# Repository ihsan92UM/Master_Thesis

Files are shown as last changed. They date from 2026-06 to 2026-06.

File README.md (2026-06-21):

# Master_Thesis

## Repository Structure
```
Master_Thesis/
├── graphics/
│   └── Contains all .png images used in markdown files
├── pcb_design_files/
│   └── Contains KiCAD 9.0 files 
├── programming_guides/
│   └── Contains programming setup and code import guide
├── stm32c0_codes/
    └── Demo code for funtional board incl. USB, I2C.
```

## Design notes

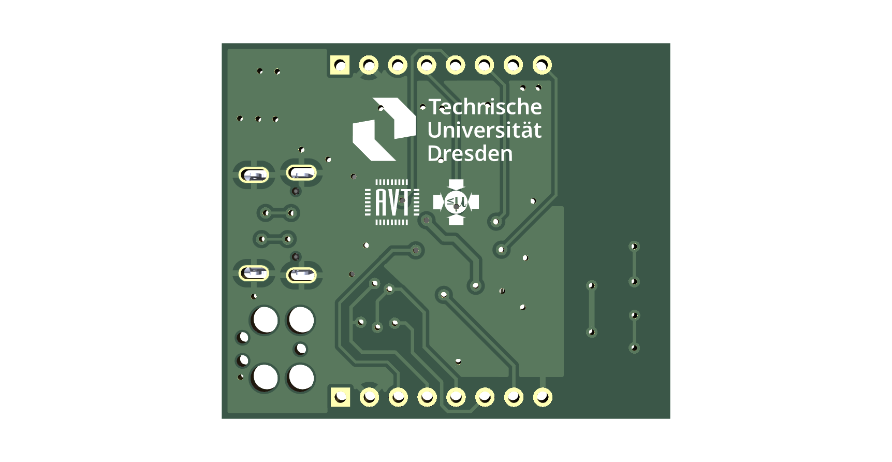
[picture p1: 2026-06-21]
pcb_design_files/func_board_jlcpcb/func_board_back_white_bw.png

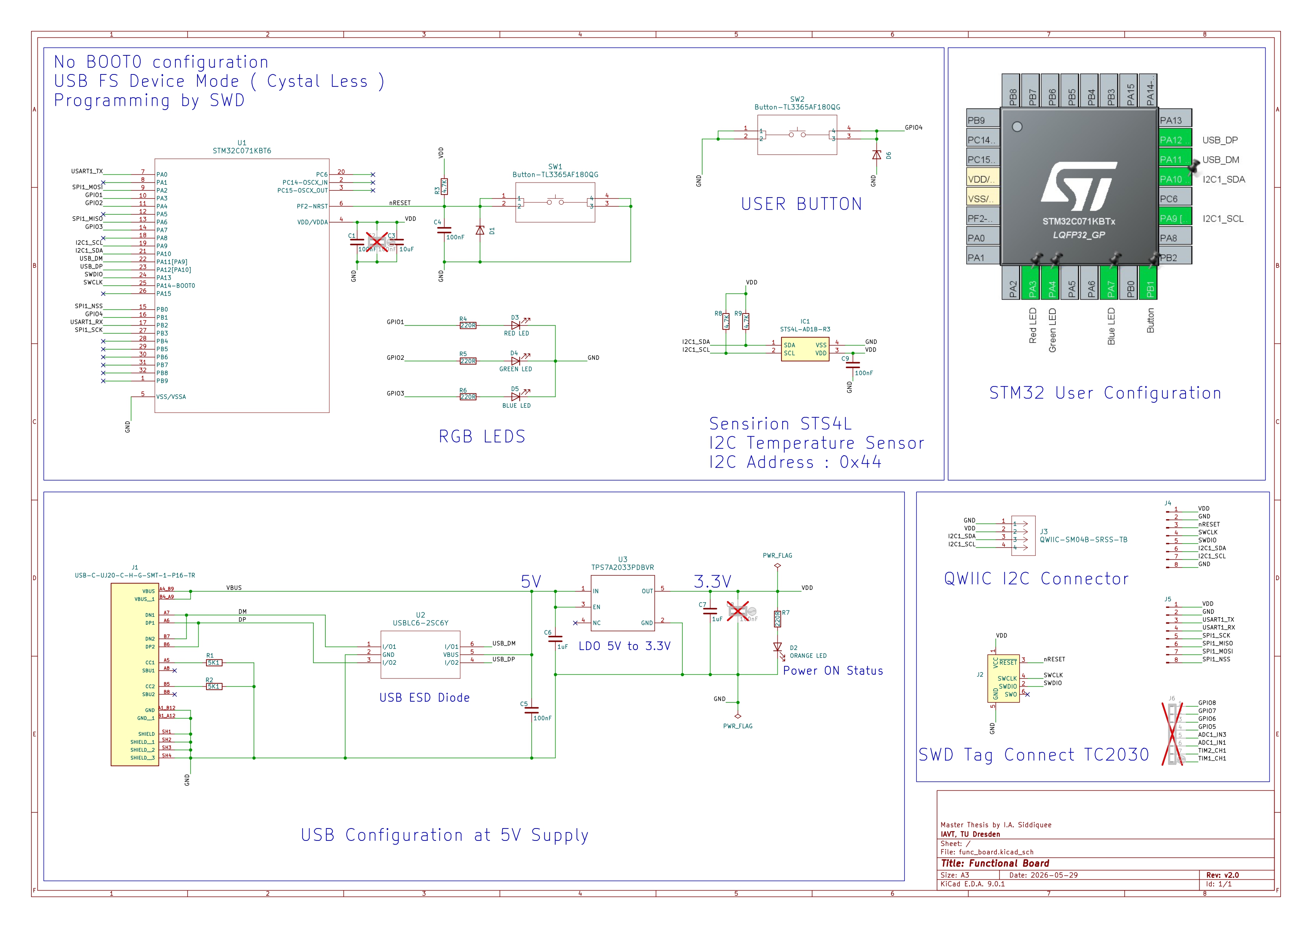
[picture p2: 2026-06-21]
pcb_design_files/func_board_jlcpcb/func_board_schematic.jpg

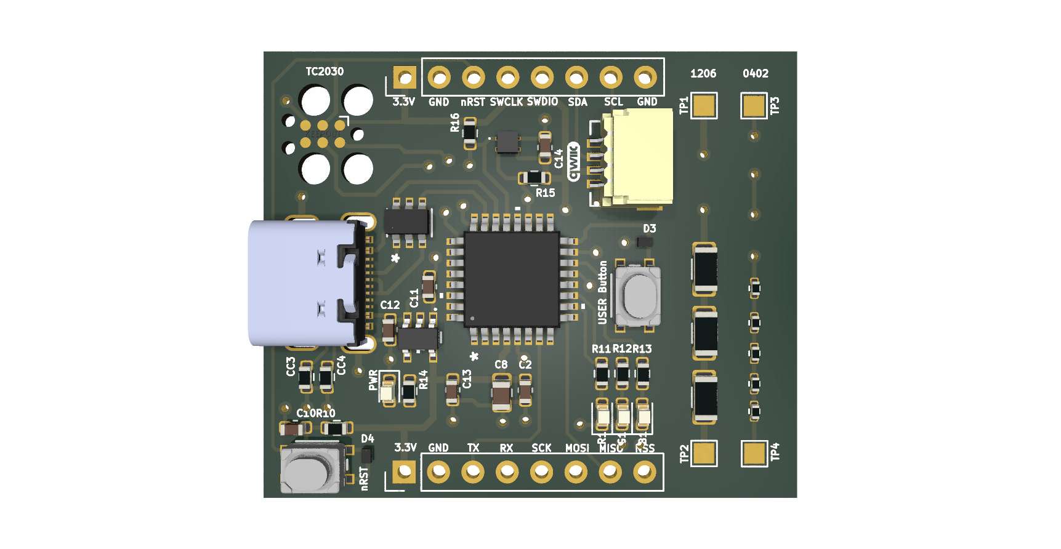
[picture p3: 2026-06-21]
pcb_design_files/func_board_jlcpcb/func_board_front_white_bw.png

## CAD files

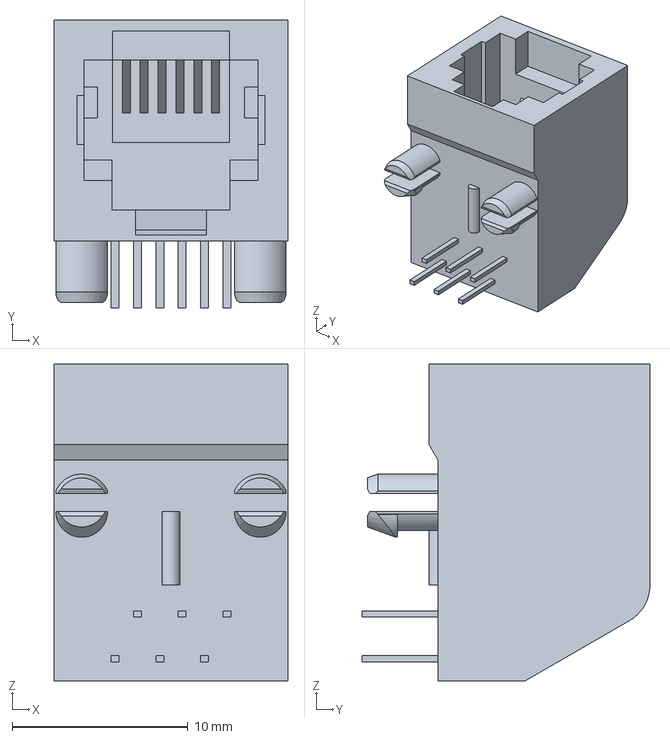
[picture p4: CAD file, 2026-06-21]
pcb_design_files/func_board_jlcpcb/Cad_files/5555165_1/c-5555165-1-e-3d.stp
13.3 x 16.4 x 18.0 mm

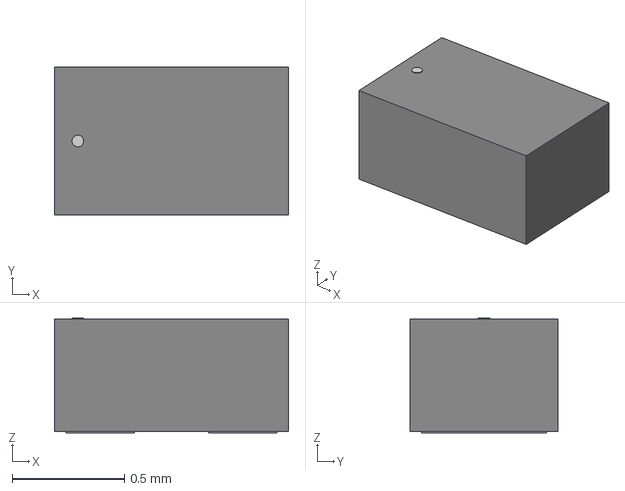
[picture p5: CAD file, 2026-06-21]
pcb_design_files/func_board_jlcpcb/Cad_files/ESDALC6V1_1M2/SOD882_STM.step
1.04 x 0.66 x 0.511 mm

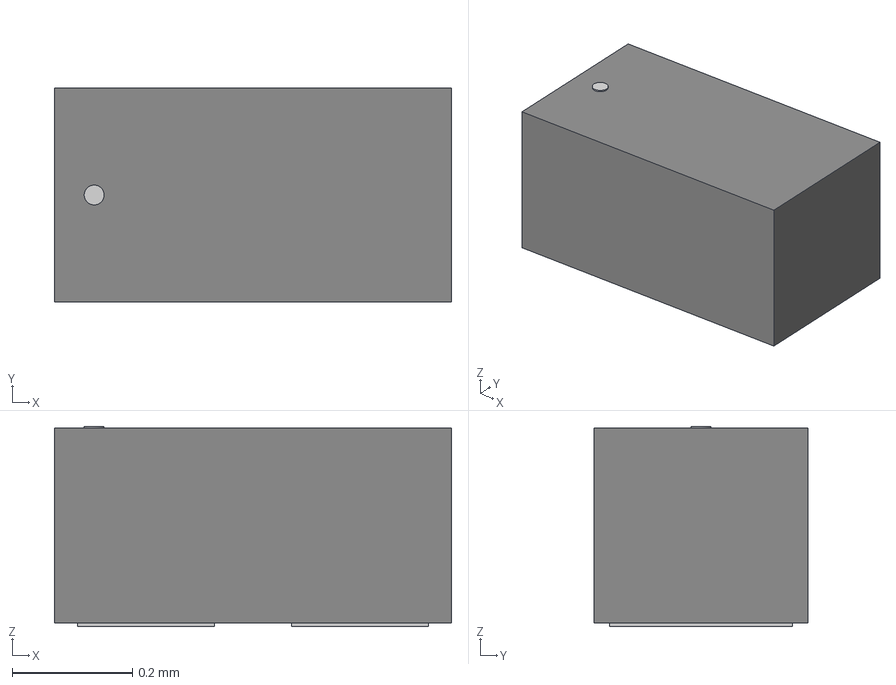
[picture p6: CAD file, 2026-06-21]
pcb_design_files/func_board_jlcpcb/Cad_files/ESDALC6V1_1U2/DIODE_ESDALC6V1-1U2_STM.step
0.66 x 0.356 x 0.333 mm

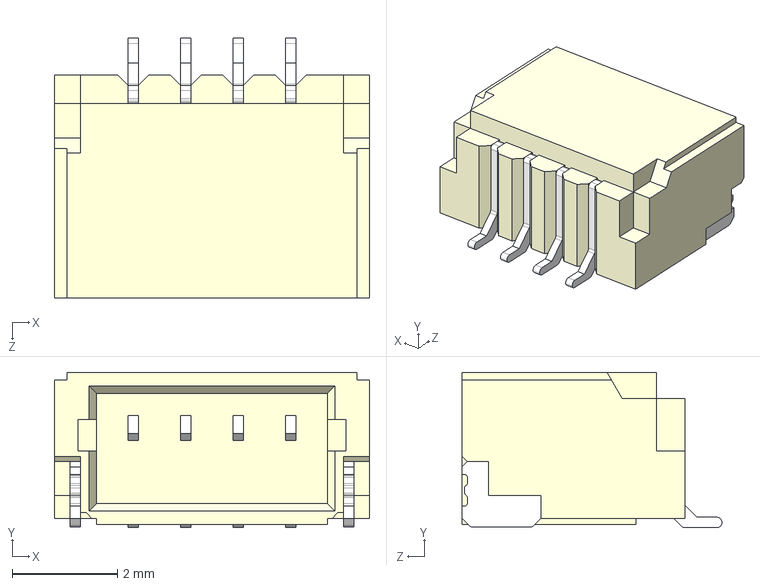
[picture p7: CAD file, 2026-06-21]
pcb_design_files/func_board_jlcpcb/Cad_files/SM04B_SRSS_TB/SM04B-SRSS-TB (LF)(SN)--3DModel-STEP-269445.STEP
6.00 x 2.96 x 4.95 mm

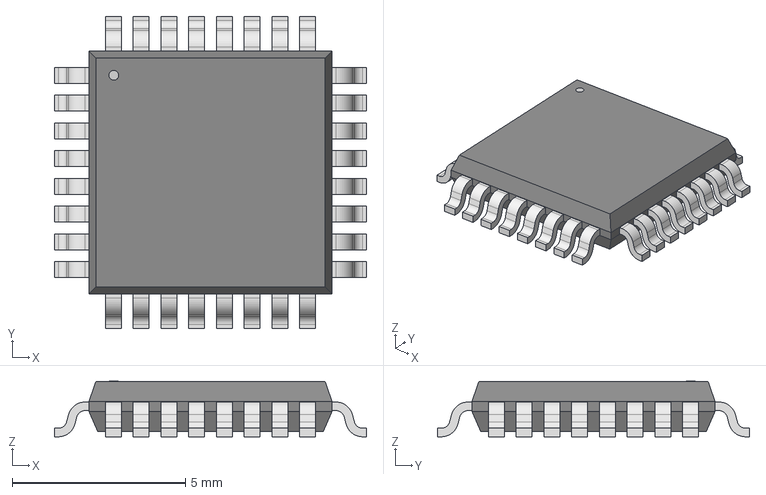
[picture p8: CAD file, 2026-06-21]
pcb_design_files/func_board_jlcpcb/Cad_files/STM32C071KBT6/LQFP-32_STM.step
8.99 x 8.99 x 1.60 mm

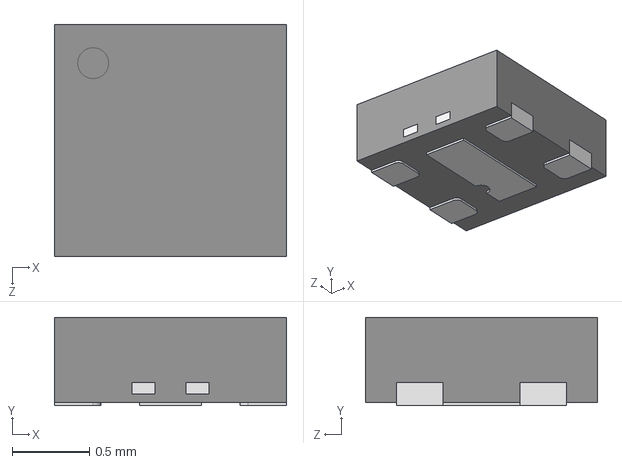
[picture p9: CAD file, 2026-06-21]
pcb_design_files/func_board_jlcpcb/Cad_files/STS40_CD1B_R3/STS40-CD1B-R3.STEP
1.50 x 0.57 x 1.50 mm

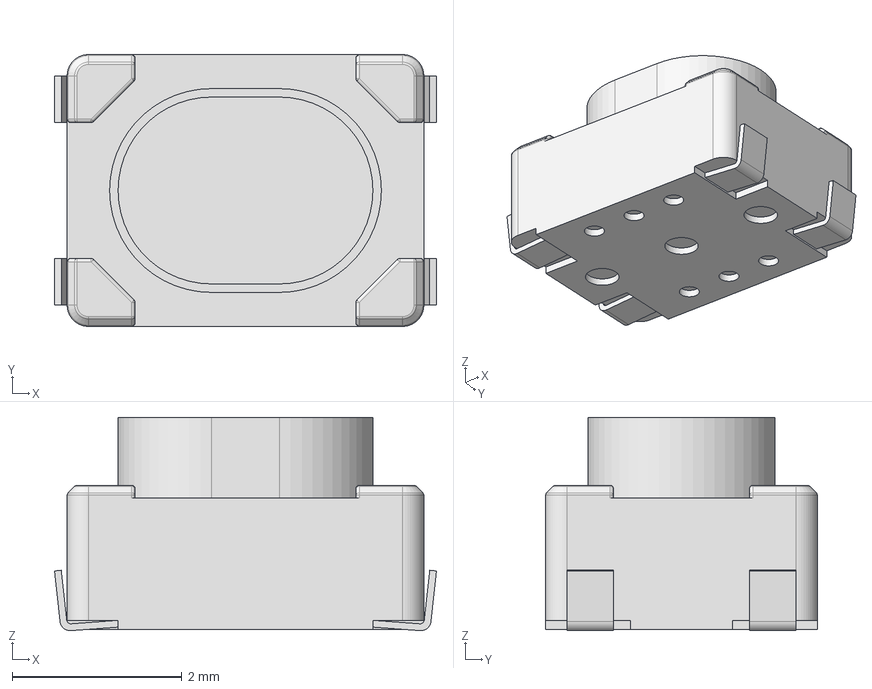
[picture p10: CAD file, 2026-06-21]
pcb_design_files/func_board_jlcpcb/Cad_files/TL3365AF180QG/TL3365AF180QG.stp
4.50 x 3.20 x 2.51 mm

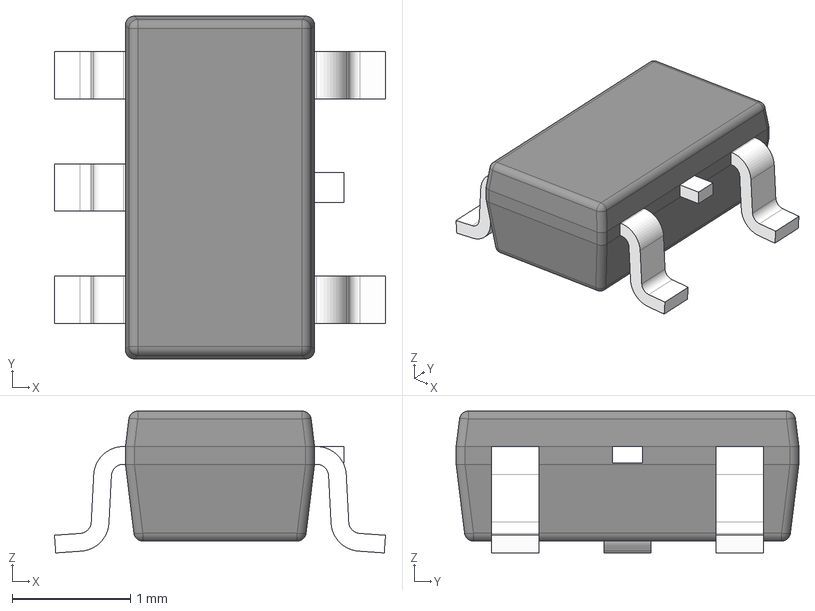
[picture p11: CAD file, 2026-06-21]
pcb_design_files/func_board_jlcpcb/Cad_files/TPS7A2033PDBVR/DBV0005A.stp
2.80 x 2.90 x 1.20 mm
BODY-SOT
LEAD-SOT x 5
LEAD-DUMMY

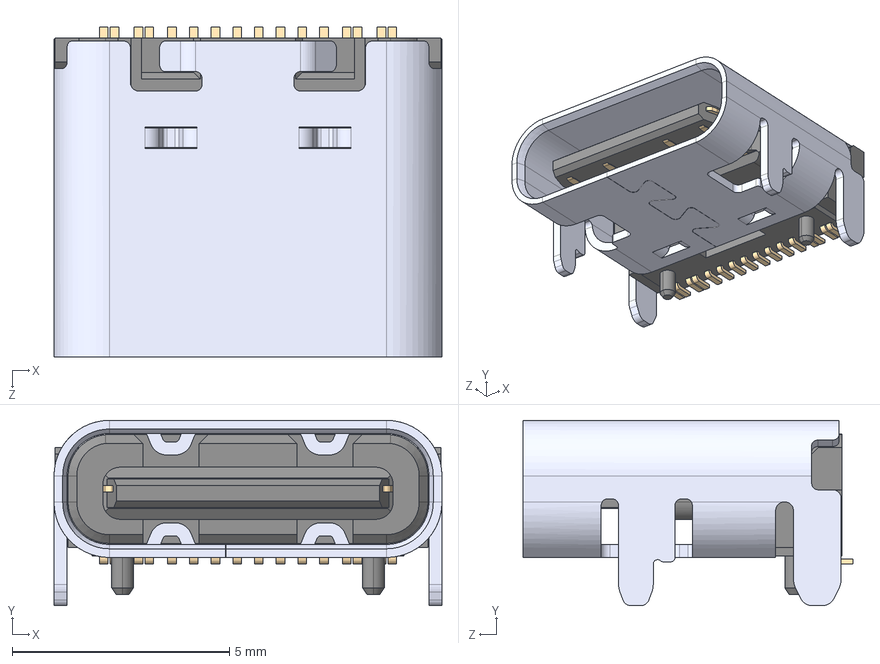
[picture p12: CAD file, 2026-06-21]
pcb_design_files/func_board_jlcpcb/Cad_files/UJ20_C_H_G_SMT_1_P16_TR/UJ20-C-H-G-SMT-1-P16-TR.step
8.94 x 4.27 x 7.60 mm

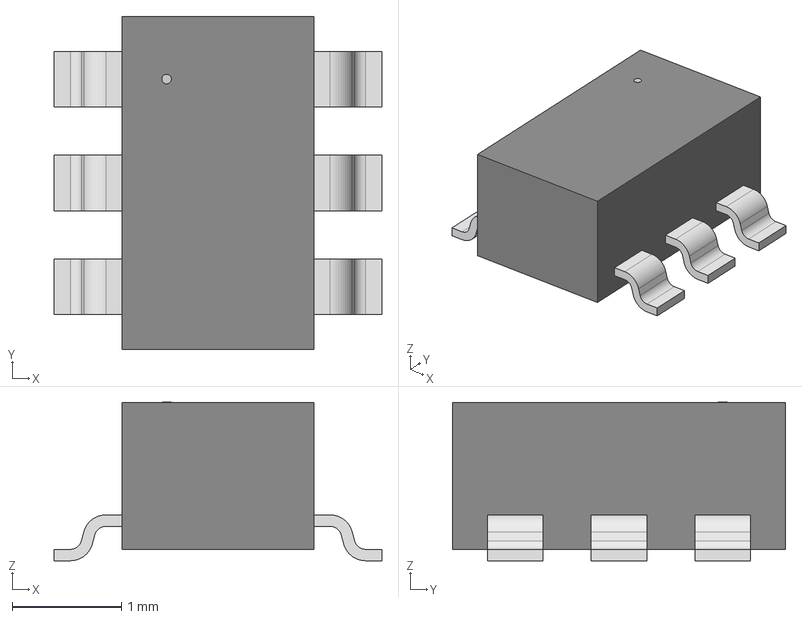
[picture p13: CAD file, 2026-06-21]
pcb_design_files/func_board_jlcpcb/Cad_files/USBLC6_2SC6Y/SOT23-6L_STM.step
3.00 x 3.05 x 1.45 mm

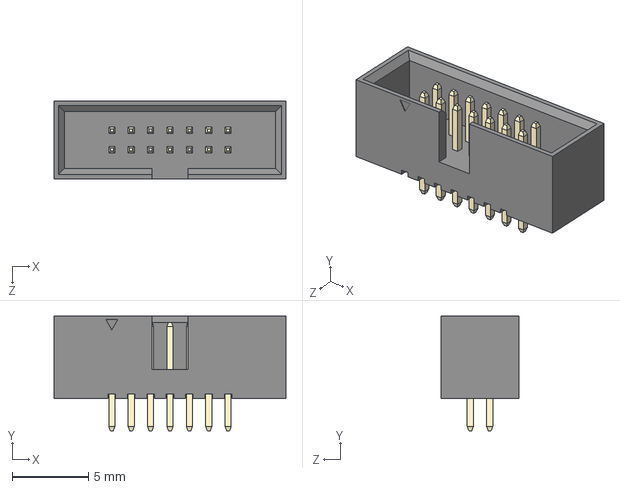
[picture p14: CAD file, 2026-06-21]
pcb_design_files/programmer_bridge/step file/3220-14-0100-00.STEP
15.2 x 7.50 x 5.10 mm
3220-xx-0100-00 body_14
Pin^3220-xx-0100-00 x 14

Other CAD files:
pcb_design_files/func_board_jlcpcb/Cad_files/LIB_STS4L-AD1B-R3/STS4L-AD1B-R3/Allegro/sts4lad1br3.psm
pcb_design_files/func_board_jlcpcb/Cad_files/LIB_STS4L-AD1B-R3/STS4L-AD1B-R3/DEHDL/sts4l_ad1b_r3/chips/chips.prt

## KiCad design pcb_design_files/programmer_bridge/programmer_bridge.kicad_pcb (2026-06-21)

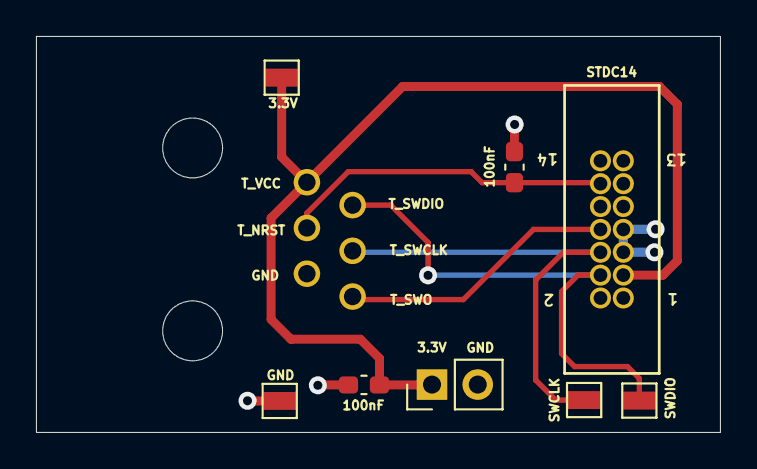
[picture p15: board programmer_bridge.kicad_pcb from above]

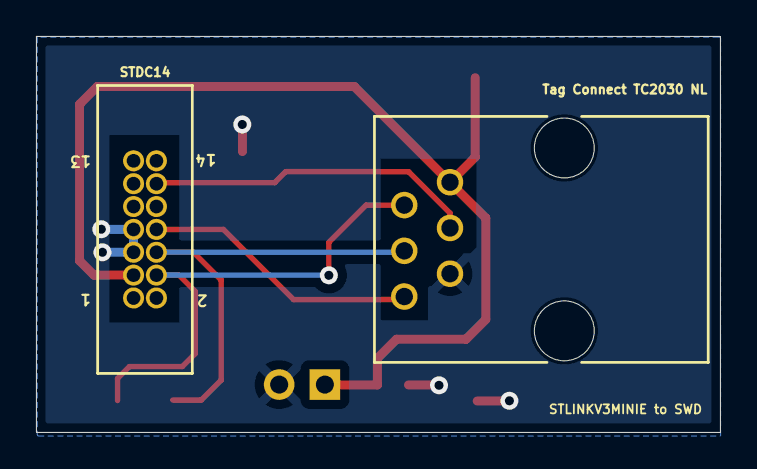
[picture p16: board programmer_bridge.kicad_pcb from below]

Board: 2 copper layers, 38.0 x 22.0 mm, 9 parts (2 on the bottom side), 6 nets.

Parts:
C4, C5: 100nF; C_0603_1608Metric_Pad1.08x0.95mm_HandSolder
J1: 5555165-1; CONN6_5555165-1_TEC
J2: 3220-14-0100-00; CONN14_3220-14_CNC
J3: Conn_01x02_Pin; PinHeader_1x02_P2.54mm_Vertical
SWCLK: TestPoint; TestPoint_Pad_1.5x1.5mm
SWDIO: TestPoint; TestPoint_Pad_1.5x1.5mm
TP3, TP6: TestPoint; TestPoint_Pad_1.5x1.5mm

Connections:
/GND: C4.2, C5.2, J1.2, J2.5, J2.7, J3.2, TP3.1
/T_NRST: C5.1, J1.4, J2.12
/T_SWCLK: J1.3, J2.6, SWCLK.1
/T_SWDIO: J1.5, J2.4, SWDIO.1
/T_SWO: J1.1, J2.8
/T_VCC: C4.1, J1.6, J2.3, J3.1, TP6.1

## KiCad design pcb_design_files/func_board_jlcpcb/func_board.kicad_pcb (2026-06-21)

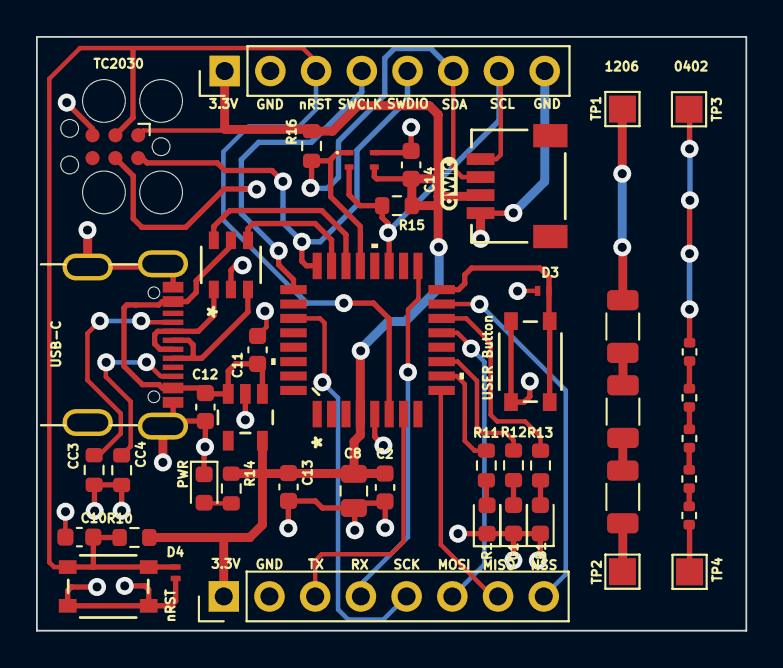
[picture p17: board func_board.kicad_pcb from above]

Board: 2 copper layers, 39.4 x 33.0 mm, 33 parts (0 on the bottom side), 28 nets.

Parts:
B1: BLUE LED; LED_0603_1608Metric
C2, C10, C11, C14: 100nF; C_0603_1608Metric
C8: 10uF; C_0805_2012Metric
C12, C13: 1uF; C_0603_1608Metric
CC3, CC4: 5K1; R_0603_1608Metric
D3, D4: ESD5Zxx; ESDALC6V1_1M2
G1: GREEN LED; LED_0603_1608Metric
IC2: STS4L-AD1B-R3; STS4LAD1BR3
J6: Conn_ARM_SWD_TagConnect_TC2030; Tag-Connect_TC2030-IDC-FP_2x03_P1.27mm_Vertical
J7: QWIIC-SM04B-SRSS-TB; CONN_SM04B-SRSS-TB_JST
J8, J9: Conn_01x08_Pin; PinHeader_1x08_P2.54mm_Vertical
PWR1: ORANGE LED; LED_0603_1608Metric
R1: RED LED; LED_0603_1608Metric
R10, R15, R16: 4.7K; R_0603_1608Metric
R11, R12, R13, R14: 220R; R_0603_1608Metric
SW3, SW4: Button-TL3365AF180QG; TL3365AF180QG_EWI
U4: STM32C071KBT6; LQFP-32_STM
U5: USBLC6-2SC6Y; SOT23-6L_STM
U6: TPS7A2033PDBVR; DBV0005A-MFG
USB-C1: USB-C-UJ20-C-H-G-SMT-1-P16-TR; SAMESKY_UJ20-C-H-G-SMT-1-P16-TR

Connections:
/DM: U5.1 (I/O1), USB-C1.A7 (DN1), USB-C1.B7 (DN2)
/DP: U5.3 (I/O2), USB-C1.A6 (DP1), USB-C1.B6 (DP2)
/GND: B1.1 (K), C2.2, C8.2, C10.2, C11.2, C12.2, C13.2, C14.2, CC3.2, CC4.2, D3.2 (A), D4.2 (A), G1.1 (K), IC2.4 (VSS), J6.5 (GND), J7.1, J8.2, J8.8, J9.2, PWR1.1 (K), R1.1 (K), SW3.3, SW3.4, SW4.1, SW4.2, U4.5 (VSS/VSSA), U5.2 (GND), U6.2 (GND), USB-C1.A1_B12 (GND), USB-C1.B1_A12 (GND__1), USB-C1.SH1 (SHIELD), USB-C1.SH2 (SHIELD__1), USB-C1.SH3 (SHIELD__2), USB-C1.SH4 (SHIELD__3)
/GPIO1: R11.1, U4.10 (PA3)
/GPIO2: R12.1, U4.11 (PA4)
/GPIO3: R13.1, U4.14 (PA7)
/GPIO4: D3.1 (K), SW4.3, SW4.4, U4.16 (PB1)
/I2C2_SCL: IC2.2 (SCL), J7.4, J8.7, R15.2, U4.19 (PA9)
/I2C2_SDA: IC2.1 (SDA), J7.3, J8.6, R16.2, U4.21 (PA10)
/SPI1_MISO: J9.6, U4.13 (PA6)
/SPI1_MOSI: J9.7, U4.9 (PA2)
/SPI1_NSS: J9.8, U4.15 (PB0)
/SPI1_SCK: J9.5, U4.27 (PB3)
/SWCLK: J6.4 (SWCLK), J8.4, U4.25 (PA14-BOOT0)
/SWDIO: J6.2 (SWDIO), J8.5, U4.24 (PA13)
/USART1_RX: J9.4, U4.17 (PB2)
/USART1_TX: J9.3, U4.7 (PA0)
/USB_DM: U4.22 (PA11[PA9]), U5.6 (I/O1)
/USB_DP: U4.23 (PA12[PA10]), U5.4 (I/O2)
/VBUS: C11.1, C12.1, U5.5 (VBUS), U6.1 (IN), U6.3 (EN), USB-C1.A4_B9 (VBUS), USB-C1.B4_A9 (VBUS__1)
/VDD: C2.1, C8.1, C13.1, C14.1, IC2.3 (VDD), J6.1 (VCC), J7.2, J8.1, J9.1, R10.2, R14.1, R15.1, R16.1, U4.4 (VDD/VDDA), U6.5 (OUT)
/nRESET: C10.1, D4.1 (K), J6.3 (~RESET), J8.3, R10.1, SW3.1, SW3.2, U4.6 (PF2-NRST)
unnamed: PWR1.2 (A), R14.2
unnamed: R1.2 (A), R11.2
unnamed: G1.2 (A), R12.2
unnamed: B1.2 (A), R13.2
unnamed: CC3.1, USB-C1.A5 (CC1)
unnamed: CC4.1, USB-C1.B5 (CC2)

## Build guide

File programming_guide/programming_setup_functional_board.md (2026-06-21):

# Programming Guide - STM32C071KBT6 based functional board 

## Requirements

#### Hardware

* Programmer : [STLINK-V3MINIE](https://www.st.com/resource/en/user_manual/um2910-stlinkv3minie-debuggerprogrammer-tiny-probe-for-stm32-microcontrollers-stmicroelectronics.pdf)
* Type-C cable
* Functional Board
* Programmer bridge
* [Tag Connect TC2030-MCP](https://www.digikey.de/de/products/detail/tag-connect-llc/TC2030-MCP/2666488)

#### Software
* [STM32CubeIDE 1.17.0](https://www.st.com/en/development-tools/stm32cubeide.html)
* [STM3CubeProgrammer](https://www.st.com/en/development-tools/stm32cubeprog.html)

# Getting Started
To program the functional board using SWD, first connect the STLINK-V3MINIE STDC14 cable to Programmer Bridge boards Female STDC14 connector. Then, Tag Connect TC2030's RJ12 Jack to the Programmer Bridge boards Female RJ12 receptor. Finally, the Tag Connect's 6pin connector to the functional board.

> [!IMPORTANT]
> Functional board has to be powered by USB-C because the STLINKV3MINIE programmer doesn't provide the board with power. The Programmer only senses the VDD and GND levels. 

Connection diagram

# Setup Validation

## STM32CubeProgrammer 

Open the `STM32CubeProgrammer` application and select `STLINK` as Interface and `Connect`. Once connected on the `Target Information` window it will list the MCU that is connected. On the `ST-LINK configuration` window it will show the target voltage level.

## Porgramming

Device can be now programmed as usual as using STM32CubeIDE.

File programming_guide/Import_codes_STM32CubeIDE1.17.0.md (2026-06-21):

# Importing Existing Code — STM32CubeIDE 1.17.0

## Requirements

### Hardware
- Functional board
- STLINK-V3MINIE programmer and Programmer Bridge
- Type-C cable

### Software
- [STM32CubeIDE 1.17.0](https://www.st.com/en/development-tools/stm32cubeide.html)
- [STM32CubeMX](https://www.st.com/en/development-tools/stm32cubemx.html)
- [STM32CubeProgrammer](https://www.st.com/en/development-tools/stm32cubeprog.html)

## Software Basics

- **STM32CubeIDE 1.17.0**: An integrated development environment (IDE) used to write, compile, debug, and run code on STM32 microcontrollers.
- **STM32CubeMX**: A graphical configuration tool for setting up pins, peripherals, and middleware, and generating initialization code for use in STM32CubeIDE.

These two tools complement each other. STM32CubeMX is typically opened within STM32CubeIDE to configure the target and generate the `.ioc` file.

# Getting Started

Download and install all three required software packages, then open **STM32CubeIDE 1.17.0**.

> [!WARNING]
> Existing STM32 code in this project was written using STM32CubeIDE version 1.17.0. Newer versions can be used, but the code may need to be migrated.

# Importing a Sample Programme

1. Launch STM32CubeIDE 1.17.0 and choose a folder as your workspace directory.  
   Workspace selection

2. After selecting the preferred folder, the STM32CubeIDE user interface will load.  
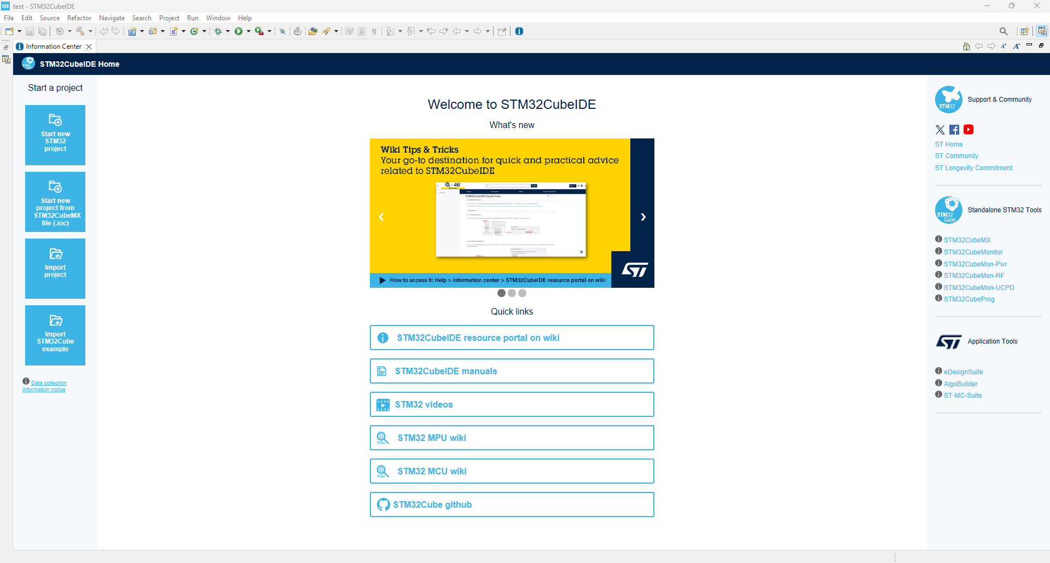
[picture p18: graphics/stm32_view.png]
STM32 default view
   

3. From the start screen, select **Import project**.  
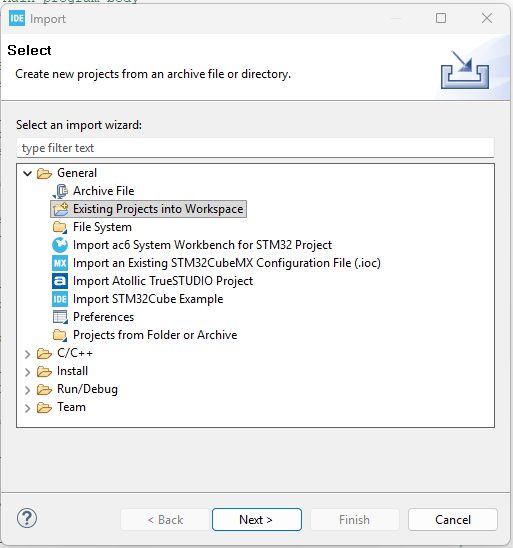
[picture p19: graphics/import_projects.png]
Import project selection
   

4. Navigate to the functional board demo code and select the options shown below.  
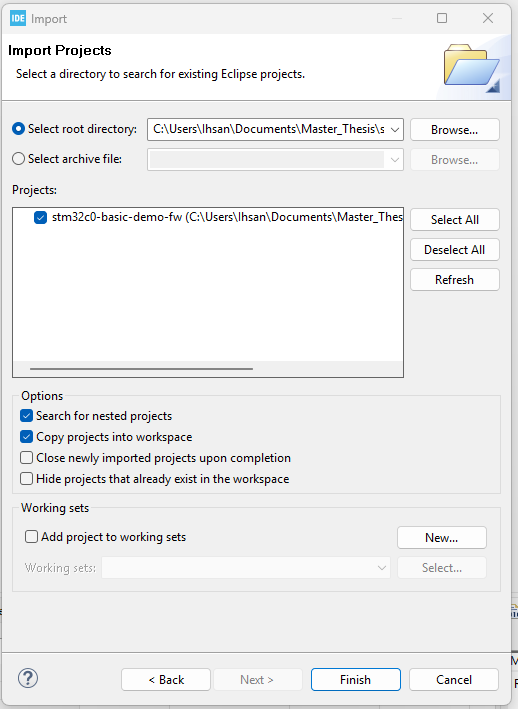
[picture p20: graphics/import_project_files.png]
File selection
   

5. Click **Finish**.

6. The project will open as **stm32c0-basic-demo-fw** in STM32CubeIDE. Navigate to the **Src** folder and open `main.c` to activate the build option.  
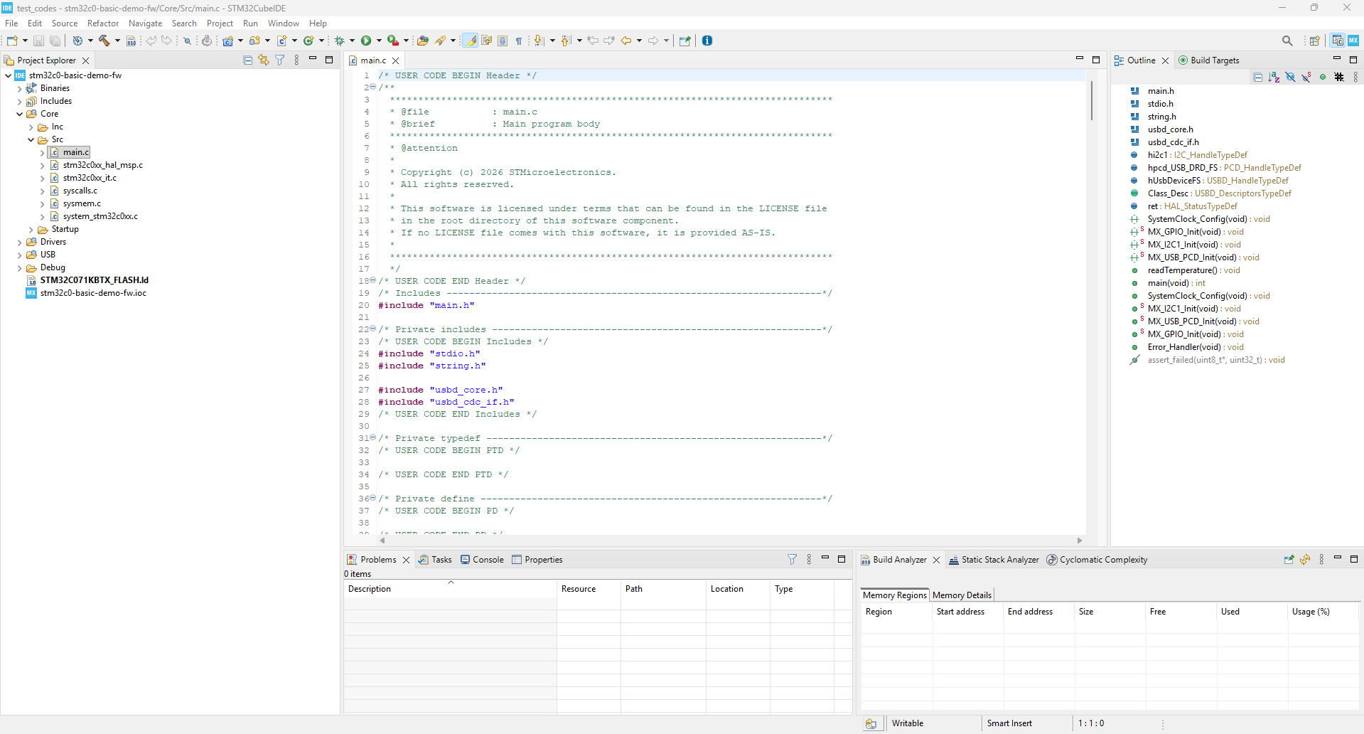
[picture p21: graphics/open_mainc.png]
Project explorer
   

7. Once `main.c` is opened, the build option becomes active. It is shown as a small hammer icon.  
   Build file

8. Click the build option to compile the code.  
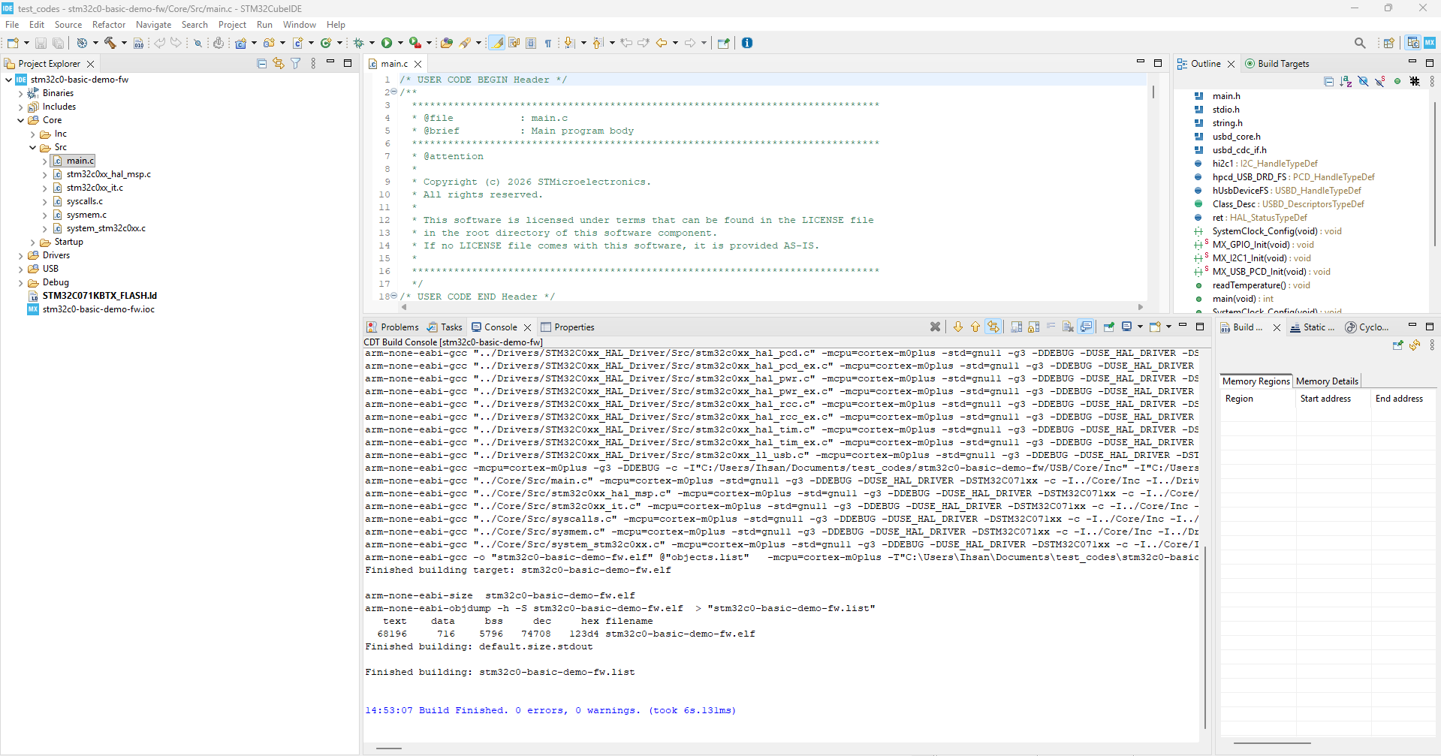
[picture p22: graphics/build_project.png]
Build console
   

9. Select the project and click **Debug** to open the debug configuration window. In the **Main** tab, the build configuration name is automatically set to the project name.  
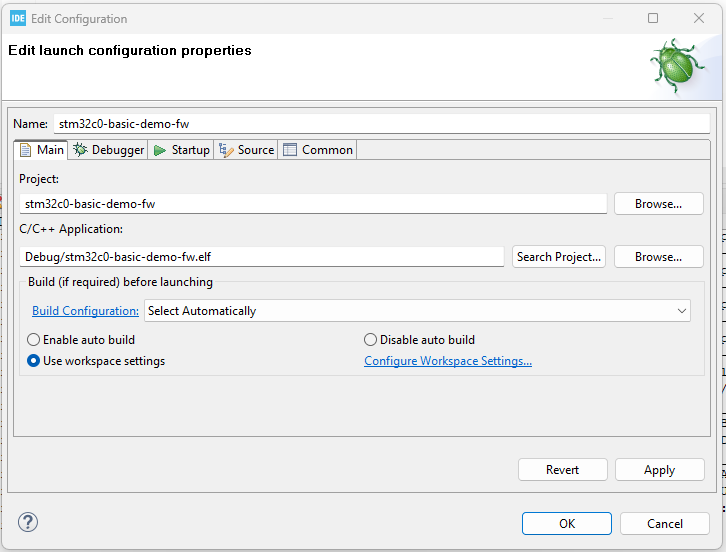
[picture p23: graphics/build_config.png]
Build configuration
   

10. Open the **Debugger** tab, select the **SWD** interface, tick **ST-LINK S/N**, click **Scan** for the Nucleo board, then click **Apply** and **OK**.  
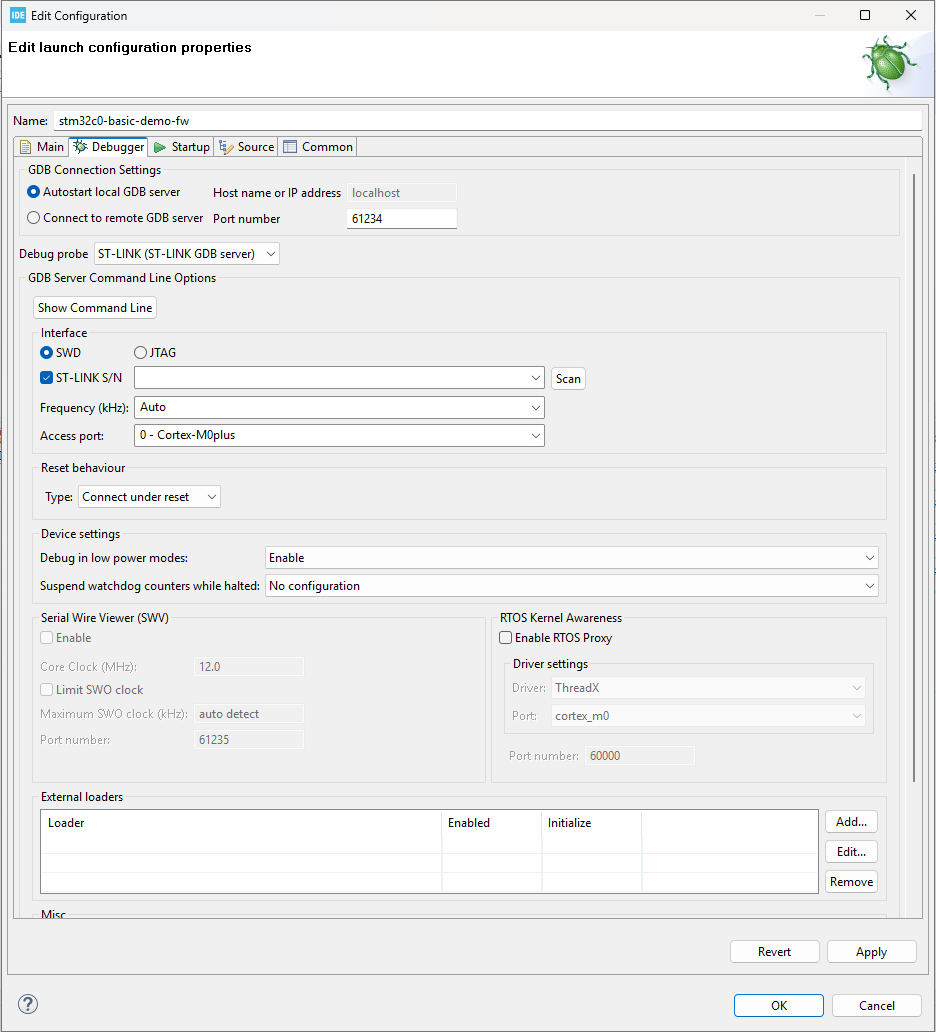
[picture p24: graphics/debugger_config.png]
Debugger configuration
    

11. The IDE will now generate and build the code before flashing it to the board. Once flashing is complete, the **Debug perspective** will open.

12. Navigate in the Debug window and step from `HAL_Init();` using the debug controls at the top of the window.

13. Stop the debugging session by clicking **Stop**. The board will then run normally.

> Note: Sometimes the USB code may fail to initialize during a debug session because step-by-step debugging is enabled. No fix has been added in the demo code.

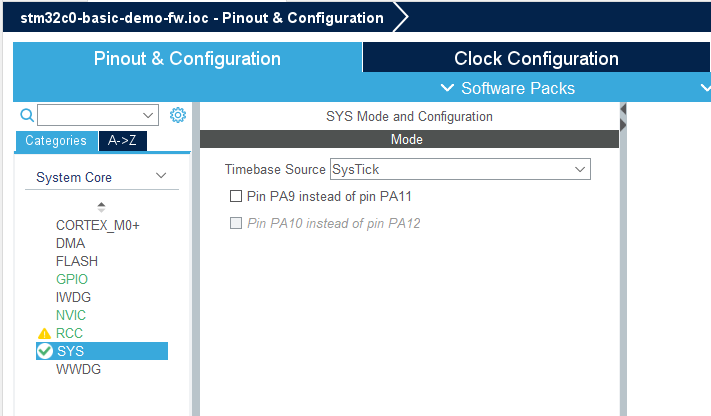
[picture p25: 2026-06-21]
graphics/sys_setup_ioc.png

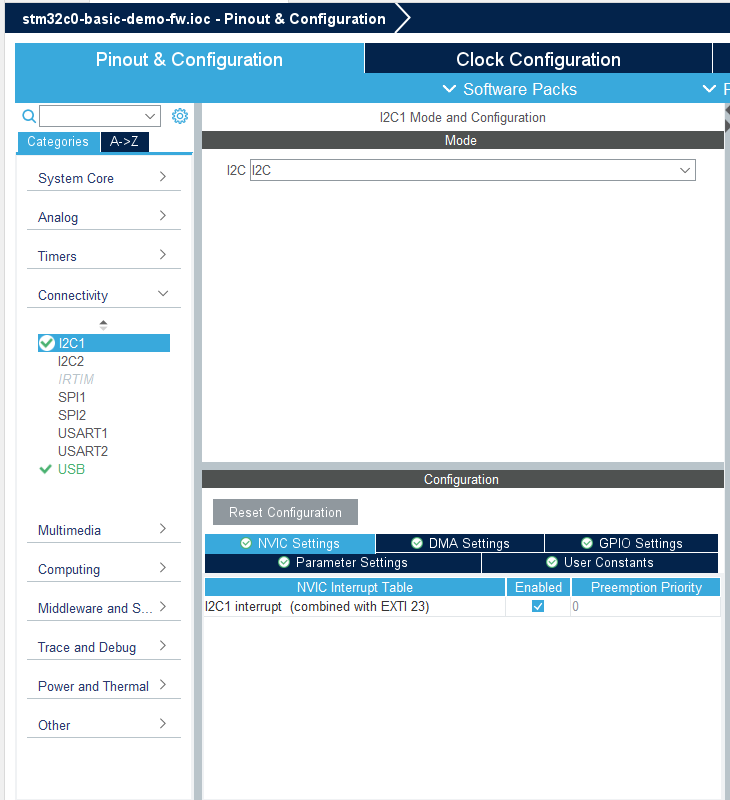
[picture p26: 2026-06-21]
graphics/i2c_setup_ioc.png

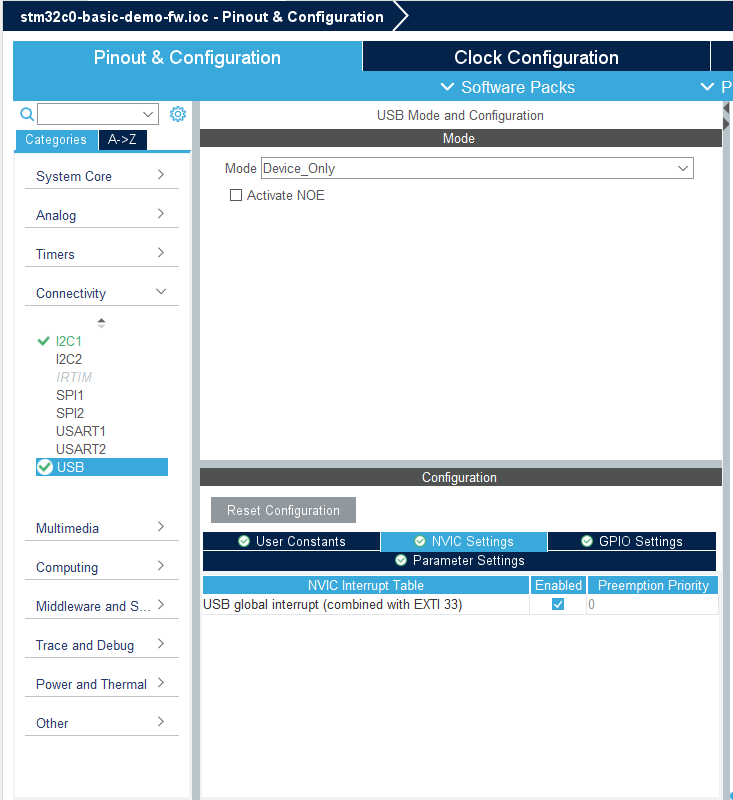
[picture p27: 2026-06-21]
graphics/usb_setup_ioc.png

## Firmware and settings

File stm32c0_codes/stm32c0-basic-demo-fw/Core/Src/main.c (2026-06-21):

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
/* Includes ------------------------------------------------------------------*/
#include "main.h"

/* USER CODE BEGIN Includes */
#include "stdio.h"
#include "string.h"

#include "usbd_core.h"
#include "usbd_cdc_if.h"
/* USER CODE END Includes */


I2C_HandleTypeDef hi2c1;

PCD_HandleTypeDef hpcd_USB_DRD_FS;

/* USER CODE BEGIN PV */
USBD_HandleTypeDef hUsbDeviceFS;
extern USBD_DescriptorsTypeDef Class_Desc;
HAL_StatusTypeDef ret;
/* USER CODE END PV */

void SystemClock_Config(void);
static void MX_GPIO_Init(void);
static void MX_I2C1_Init(void);
static void MX_USB_PCD_Init(void);
/* USER CODE BEGIN 0 */
void readTemperature() {

    uint8_t tx_data[1] = {0xFD};
    uint8_t rx_data[3];
    uint16_t DevAddress = 0x44 << 1;

    uint8_t msg[32];
    HAL_StatusTypeDef ret;

    while (HAL_I2C_GetState(&hi2c1) != HAL_I2C_STATE_READY)
    {
        //uint8_t txt[] = "ok!\r\n";
        //TEMPLATE_Transmit(txt, sizeof(txt) - 1);
    }

    ret = HAL_I2C_Master_Transmit(&hi2c1, DevAddress, tx_data, 1, 5000);
    if (ret != HAL_OK) {
        uint8_t txt[] = "TX error!\r\n";
        TEMPLATE_Transmit(txt, sizeof(txt) - 1);
    }

    HAL_Delay(10);

    ret = HAL_I2C_Master_Receive(&hi2c1, DevAddress, rx_data, 3, 5000);
    if (ret != HAL_OK) {
        uint8_t txt[] = "RX error!\r\n";
        TEMPLATE_Transmit(txt, sizeof(txt) - 1);
    }

    uint16_t t_ticks = (rx_data[0] << 8) | rx_data[1];

    // Temperature in centi-degrees (×100)
    int32_t temp = -4500 + (17500 * t_ticks) / 65535;

    // Convert to string manually
    int i = 0;

    // Add label
    const char *label = "Temperature: ";
    while (*label) msg[i++] = *label++;

    // Handle negative
    if (temp < 0) {
        msg[i++] = '-';
        temp = -temp;
    }

    // Integer part
    int32_t int_part = temp / 100;
    int32_t frac_part = temp % 100;

    // Convert integer part
    char buf[10];
    int j = 0;
    do {
        buf[j++] = (int_part % 10) + '0';
        int_part /= 10;
    } while (int_part > 0);

    while (j--) msg[i++] = buf[j];

    // Decimal part
    msg[i++] = '.';
    msg[i++] = (frac_part / 10) + '0';
    msg[i++] = (frac_part % 10) + '0';

    // Unit + newline
    msg[i++] = ' ';
    msg[i++] = 0xC2;   // UTF-8 degree symbol part 1
    msg[i++] = 0xB0;   // UTF-8 degree symbol part 2
    msg[i++] = 'C';
    msg[i++] = '\r';
    msg[i++] = '\n';

    TEMPLATE_Transmit(msg, i);
}

/* USER CODE END 0 */

/**
  * @brief  The application entry point.
  * @retval int
  */
int main(void)
{

  /* USER CODE BEGIN 1 */
	  uint8_t TxMessageBuffer[] = "hello world! \r\n";
  /* USER CODE END 1 */

  /* MCU Configuration--------------------------------------------------------*/

  /* Reset of all peripherals, Initializes the Flash interface and the Systick. */
  HAL_Init();

  /* Configure the system clock */
  SystemClock_Config();

  /* Initialize all configured peripherals */
  MX_GPIO_Init();
  MX_I2C1_Init();
  MX_USB_PCD_Init();
  /* USER CODE BEGIN 2 */
  while(hUsbDeviceFS.pClassData != NULL)
  HAL_Delay(100);

  HAL_GPIO_WritePin(GPIOA, GPIO_PIN_3, GPIO_PIN_SET);
  HAL_GPIO_WritePin(GPIOA, GPIO_PIN_4, GPIO_PIN_SET);
  HAL_GPIO_WritePin(GPIOA, GPIO_PIN_7, GPIO_PIN_SET);

  /* USER CODE END 2 */

  /* Infinite loop */
  /* USER CODE BEGIN WHILE */
  while (1)
  {
    /* USER CODE END WHILE */

    /* USER CODE BEGIN 3 */
	  readTemperature();
	  HAL_Delay(200);
	  if(HAL_GPIO_ReadPin (GPIOB, GPIO_PIN_1) == GPIO_PIN_RESET)
	  {
			TEMPLATE_Transmit(TxMessageBuffer, sizeof(TxMessageBuffer));
			HAL_Delay(250);
	  }
	  else
	  {
	  }

  }
  /* USER CODE END 3 */
}

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


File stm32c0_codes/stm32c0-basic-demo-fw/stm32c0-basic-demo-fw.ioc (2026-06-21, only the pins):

Mcu.UserName=STM32C071KBTx
PA3.GPIO_Label=Red LED
PA3.Signal=GPIO_Output
PA4.GPIO_Label=Green LED
PA4.Signal=GPIO_Output
PA7.GPIO_Label=Blue LED
PA7.Signal=GPIO_Output
PB1.GPIO_Label=Button
PB1.Signal=GPIO_Input

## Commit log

2026-06-21 added codes
    added stm32c0 basic functionality code
2026-06-21 added new files
    import code guide, kicad 9.0 files for functional board and programmer bridge
    [3220-14-0100-00.STEP, DBV0005A.stp, DIODE_ESDALC6V1-1U2_STM.step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]
2026-06-21 Fix image paths in STM32CubeIDE import guide
    Updated image paths to use lowercase 'graphics' directory.

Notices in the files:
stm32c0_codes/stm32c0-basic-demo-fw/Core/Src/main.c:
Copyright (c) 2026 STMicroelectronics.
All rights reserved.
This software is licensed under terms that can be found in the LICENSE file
